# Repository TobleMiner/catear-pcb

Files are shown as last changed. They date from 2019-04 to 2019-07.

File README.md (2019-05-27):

Nekomimi PCB
============

This repo contains the PCB for the Nekomimi project of @BenBE . It will be used
to illuminate 3D printed catears.

This is a short Video of two RevA circuit boards wired up for testing:  

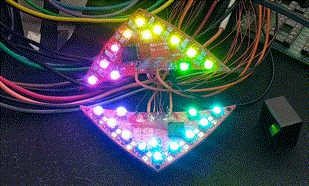
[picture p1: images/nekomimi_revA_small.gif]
RevA PCB pair in action


# PCB top
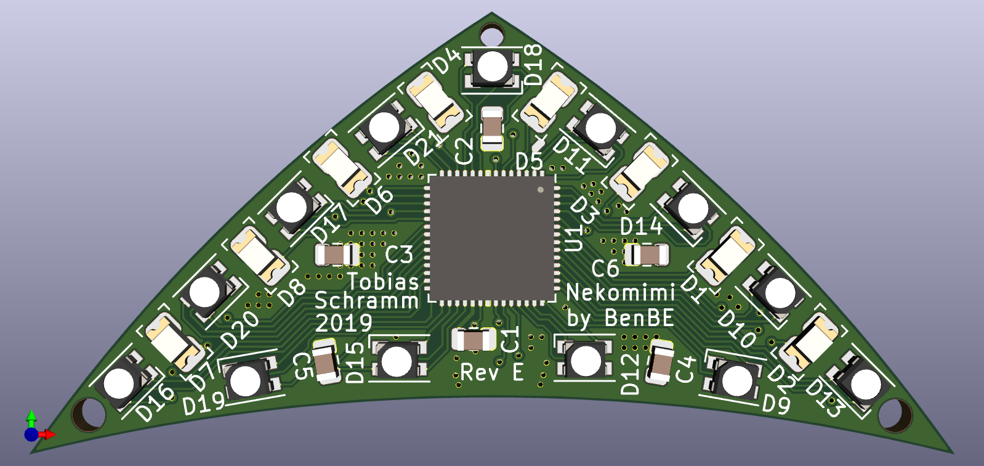
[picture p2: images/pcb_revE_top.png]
PCB RevC top


# PCB bottom
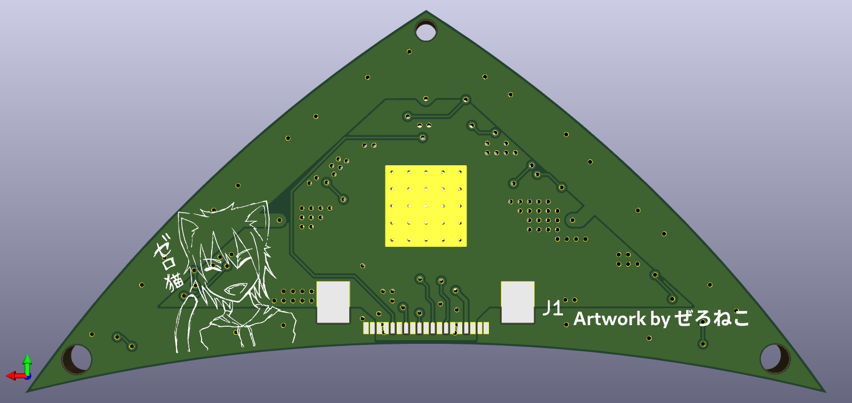
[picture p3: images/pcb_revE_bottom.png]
PCB RevC bottom


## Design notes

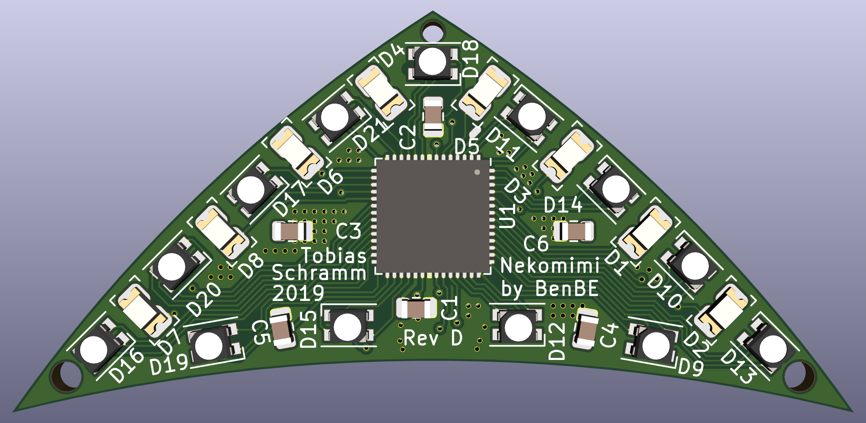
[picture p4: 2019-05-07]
images/pcb_revD_top.png

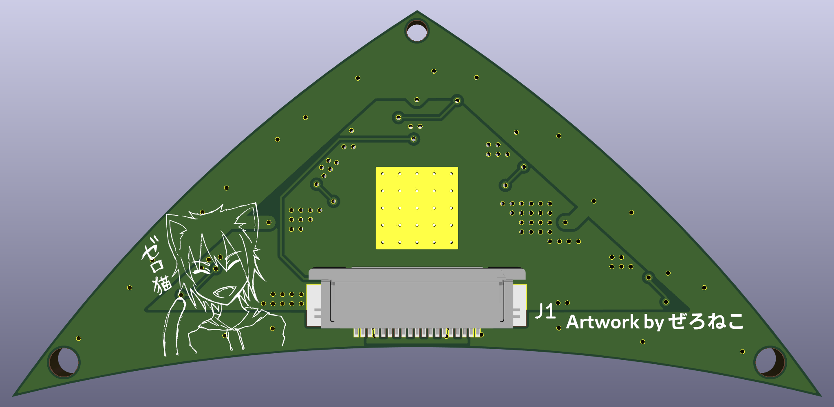
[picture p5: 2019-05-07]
images/pcb_revD_bottom.png

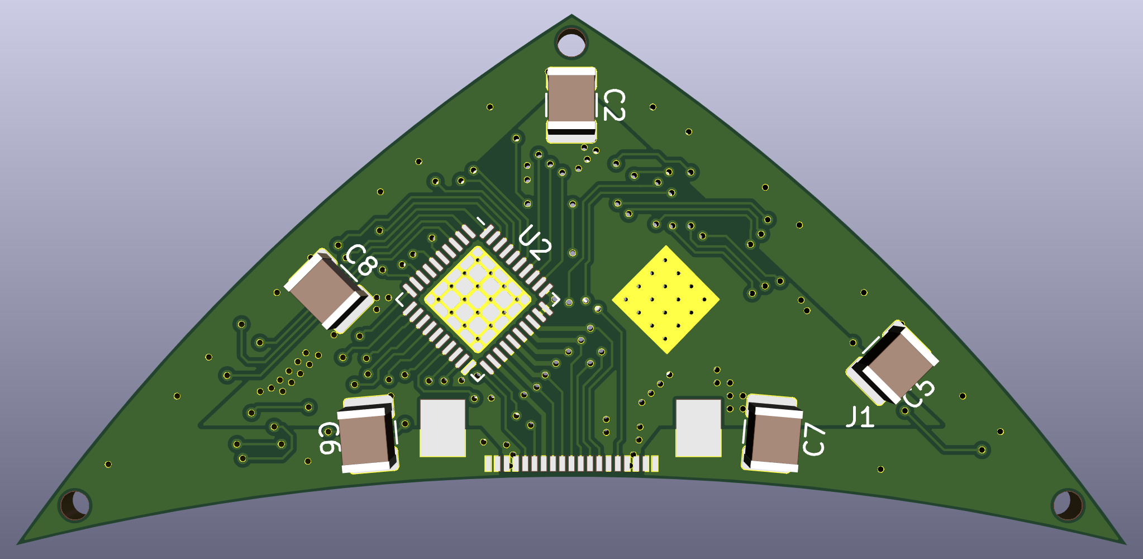
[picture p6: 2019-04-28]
images/pcb_revC_bottom.png

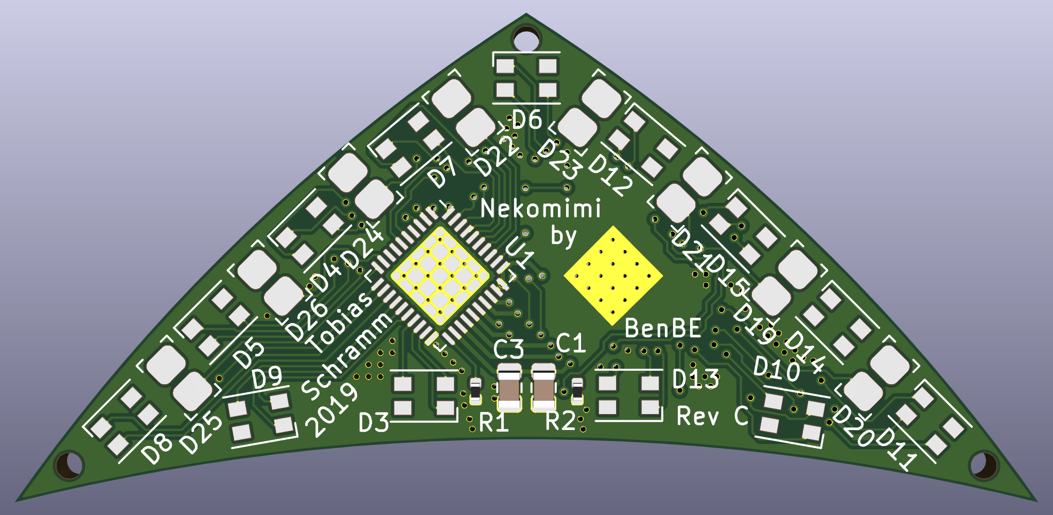
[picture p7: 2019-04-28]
images/pcb_revC_top.png

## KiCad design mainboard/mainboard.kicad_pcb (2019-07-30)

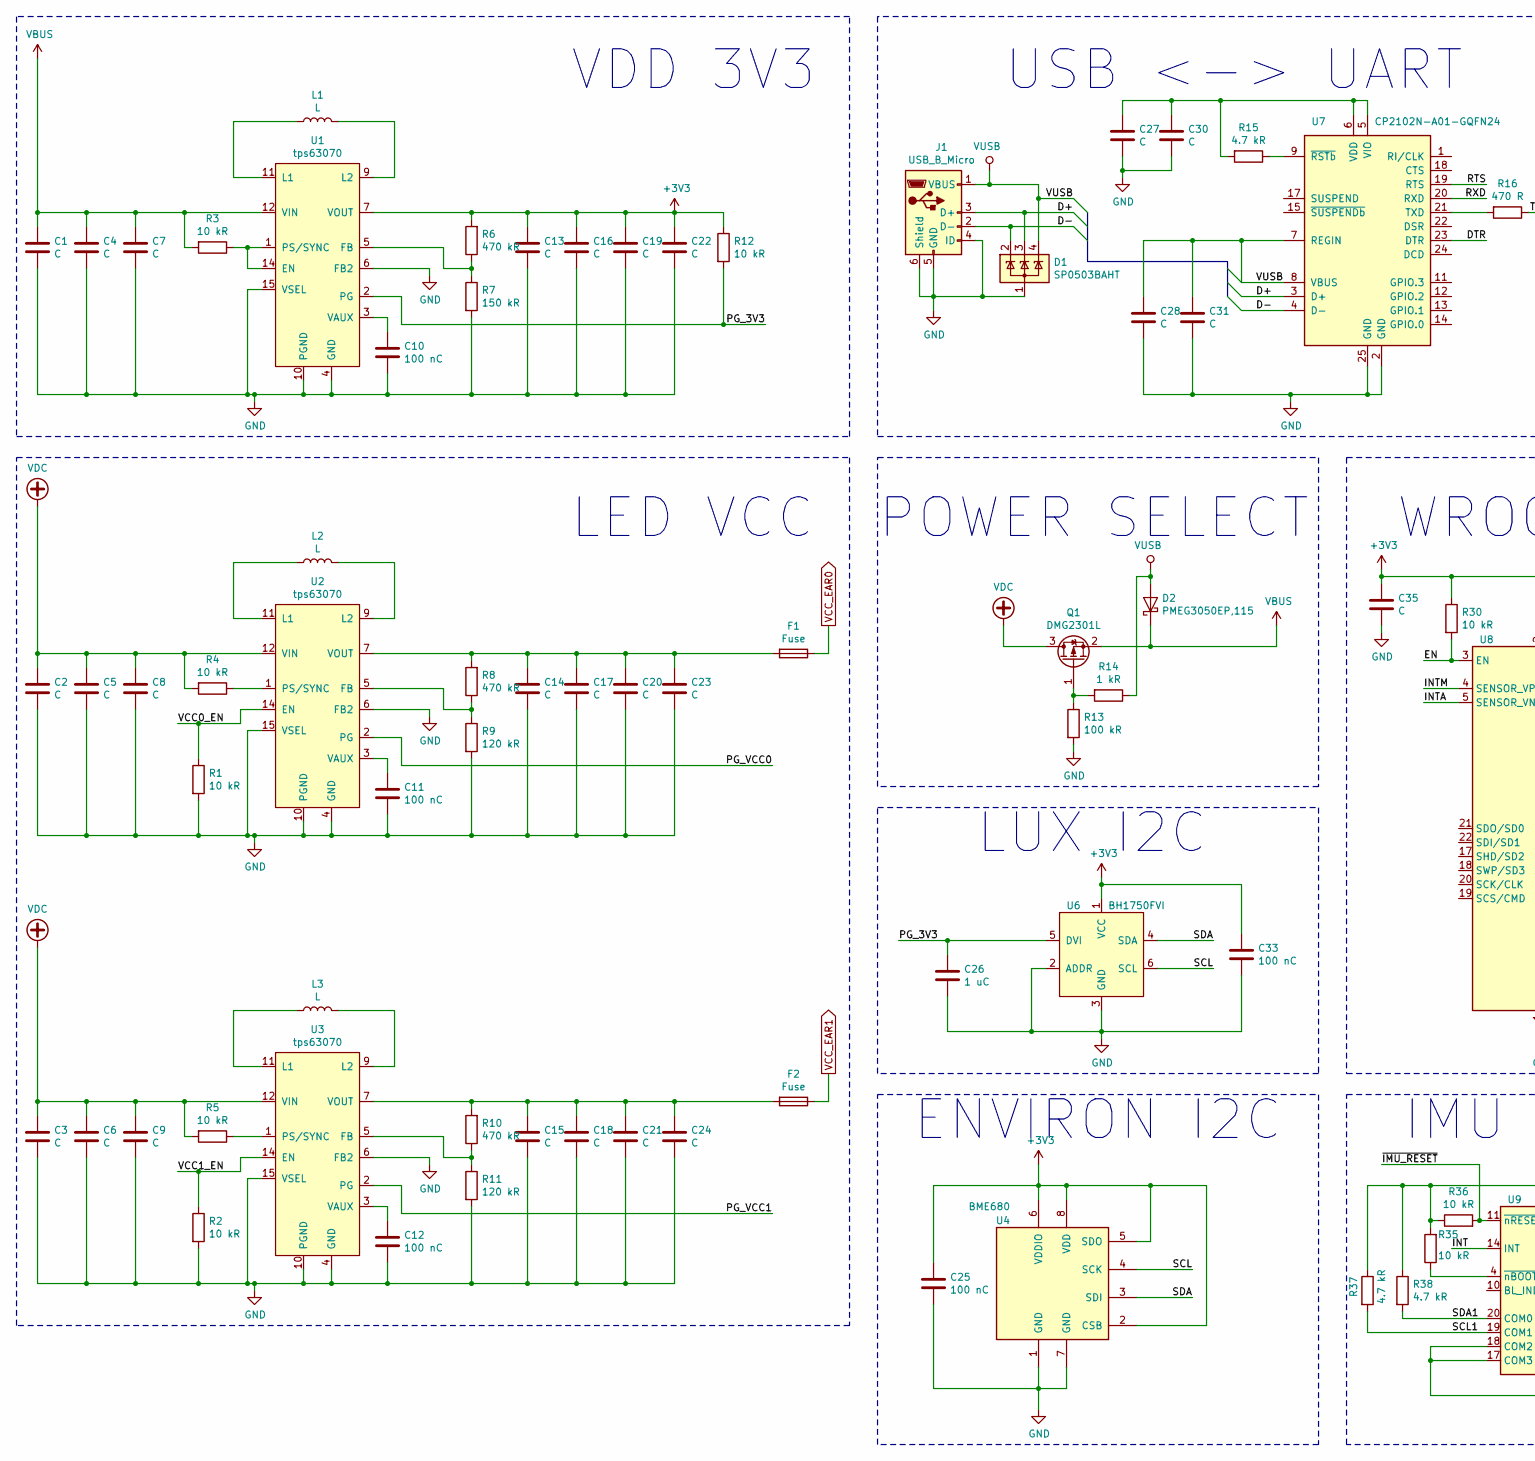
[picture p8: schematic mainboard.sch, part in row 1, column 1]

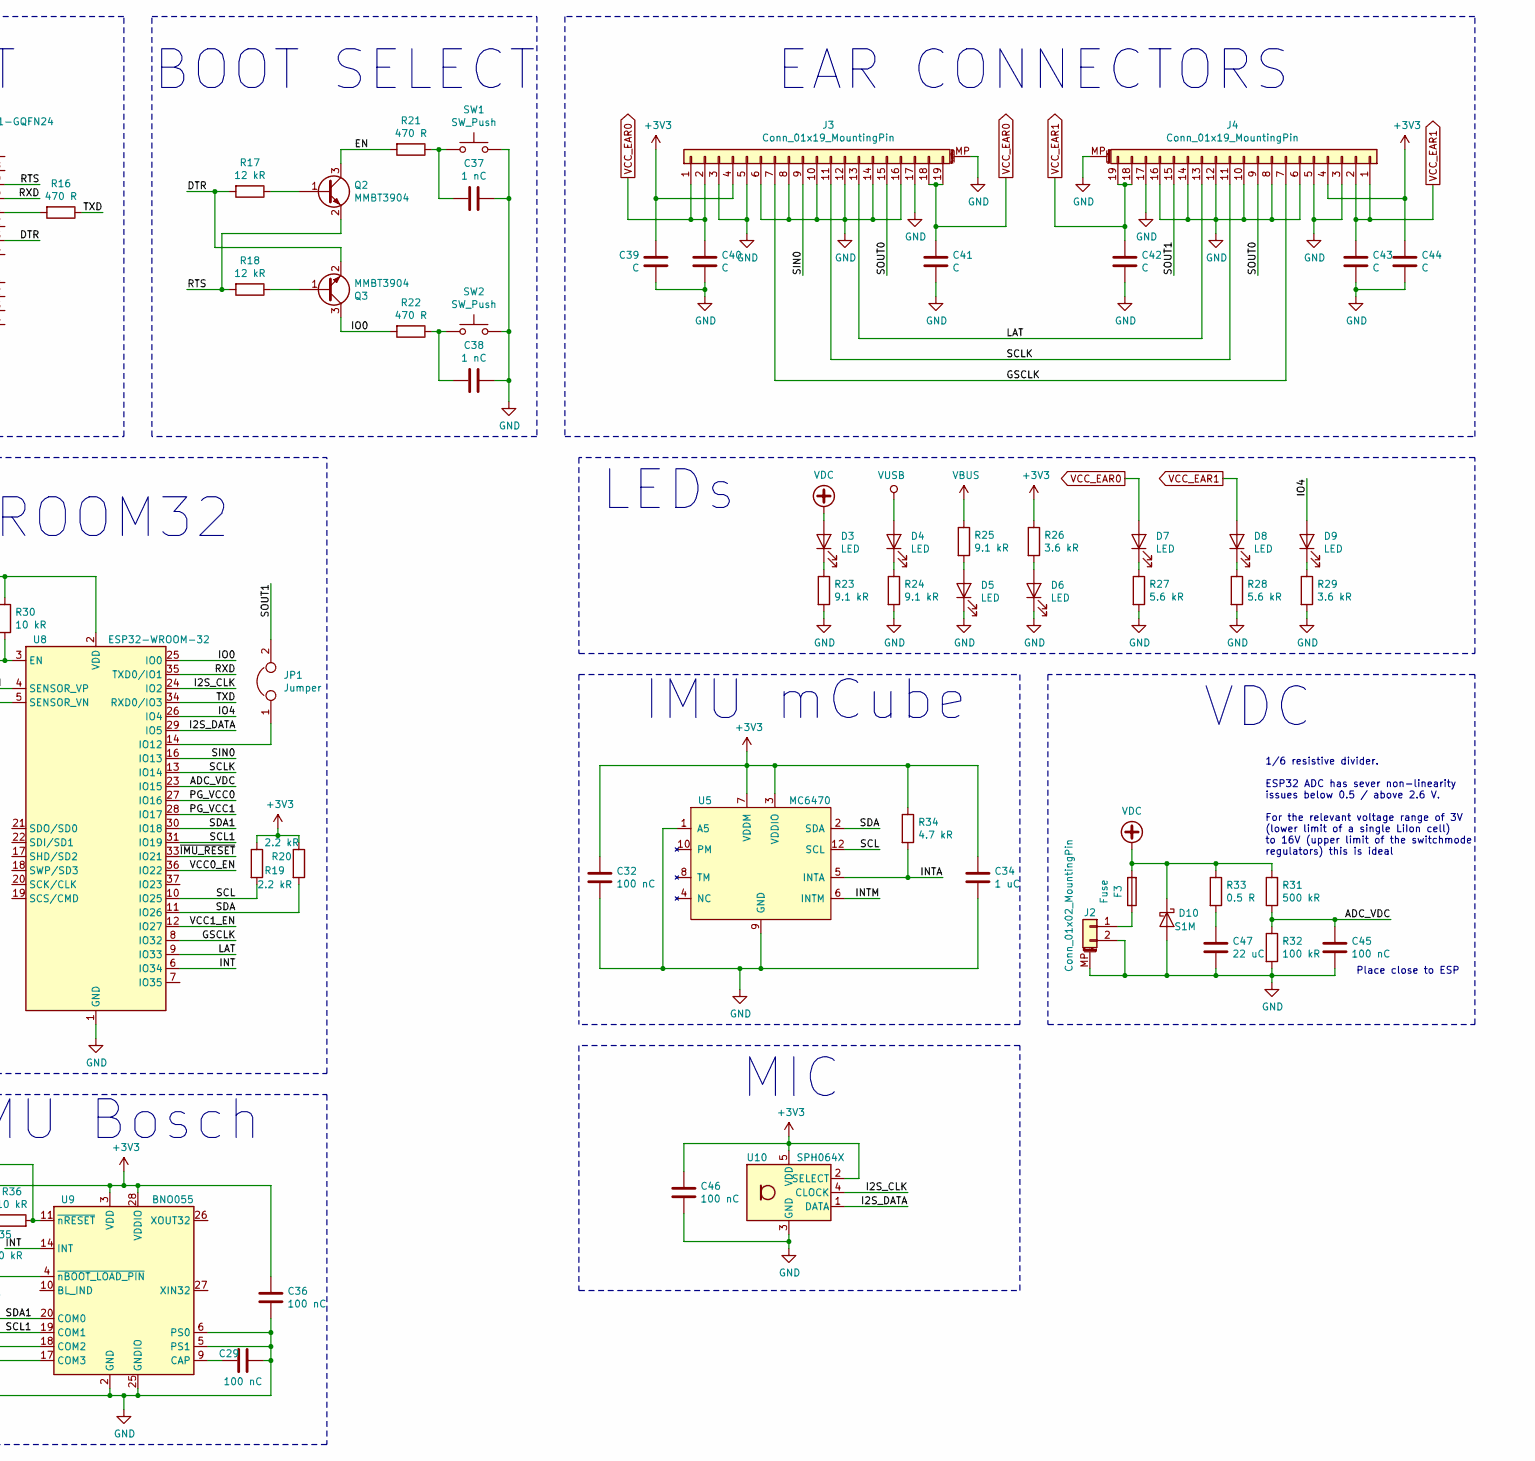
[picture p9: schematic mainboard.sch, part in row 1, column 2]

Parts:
C1, C2, C3, C4, C5, C6, C16, C17, C18, C19, C20, C21, C22, C23, C24, C27, C28, C30, C31, C35, C39, C40, C41, C42, C43, C44: C; C_0805_2012Metric
C7, C8, C9, C13, C14, C15: C; C_0603_1608Metric
C10, C11, C12, C25, C29, C32, C33, C36, C45, C46: 100 nC; C_0805_2012Metric
C26, C34: 1 uC; C_0805_2012Metric
C37, C38: 1 nC; C_0805_2012Metric
C47: 22 uC; C_1210_3225Metric
D1: SP0503BAHT; SOT-143
D2: PMEG3050EP,115; SOD-128-2
D3, D4, D5, D6, D7, D8, D9: LED; LED_0805_2012Metric
D10: S1M; D_SMA
F1, F2: Fuse; Fuse_0805_2012Metric
F3: Fuse; Fuse_1206_3216Metric
J1: USB_B_Micro; USB_Micro-B_Amphenol_10103594-0001LF_Horizontal
J2: Conn_01x02_MountingPin; XT30PW
J3, J4: Conn_01x19_MountingPin; Molex_Easy-On_52746-1971_1x19_P0.5mm_Horizontal
JP1: Jumper; SolderJumper-2_P1.3mm_Bridged_Pad1.0x1.5mm
L1, L2, L3: L; L_Coilcraft_XxL4020
Q1: DMG2301L; SOT-23
Q2, Q3: MMBT3904; SOT-23
R1, R2, R3, R4, R5, R12, R30, R35, R36: 10 kR; R_0805_2012Metric
R6, R8, R10: 470 kR; R_0805_2012Metric
R7: 150 kR; R_0805_2012Metric
R9, R11: 120 kR; R_0805_2012Metric
R13, R32: 100 kR; R_0805_2012Metric
R14: 1 kR; R_0805_2012Metric
R15, R34, R37, R38: 4.7 kR; R_0805_2012Metric
R16, R21, R22: 470 R; R_0805_2012Metric
R17, R18: 12 kR; R_0805_2012Metric
R19, R20: 2.2 kR; R_0805_2012Metric
R23, R24, R25: 9.1 kR; R_0805_2012Metric
R26, R29: 3.6 kR; R_0805_2012Metric
R27, R28: 5.6 kR; R_0805_2012Metric
R31: 500 kR; R_0805_2012Metric
R33: 0.5 R; R_1210_3225Metric
SW1, SW2: SW_Push; SW_Push_SPST_NO_Alps_SKRK
U1, U2, U3: tps63070; VQFN-HR-15
U4: BME680; Bosch_LGA-8_3x3mm_P0.8mm_ClockwisePinNumbering
U5: MC6470; LGA-12_2x2mm_P0.5mm
U6: BH1750FVI; WSOF6I
U7: CP2102N-A01-GQFN24; QFN-24-1EP_4x4mm_P0.5mm_EP2.6x2.6mm
U8: ESP32-WROOM-32
U9: BNO055; LGA-28_5.2x3.8mm_P0.5mm
U10: SPH064X

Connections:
+3V3: C13.1, C16.1, C19.1, C22.1, C25.1, C32.1, C33.1, C34.1, C35.1, C36.1, C39.1, C44.1, C46.1, J3.4, J4.4, R6.2, R12.1, R19.1, R20.1, R26.1, R30.1, R34.1, R35.2, R36.1, R37.1, R38.1, U1.7 (VOUT), U4.2 (CSB), U4.5 (SDO), U4.6 (VDDIO), U4.8 (VDD), U5.3 (VDDIO), U5.7 (VDDM), U6.1 (VCC), U8.2 (VDD), U9.3 (VDD), U9.28 (VDDIO), U10.2 (SELECT), U10.5 (VDD)
/ADC_VDC: C45.1, R31.1, R32.1, U8.23 (IO15)
/D+: D1.3 (K), J1.3 (D+), U7.3 (D+)
/D-: D1.2 (K), J1.2 (D-), U7.4 (D-)
/DTR: Q3.2 (E), R17.2, U7.23 (DTR)
/EN: Q2.3 (C), R21.2, R30.2, U8.3 (EN)
/GSCLK: J3.7, J4.7, U8.8 (IO32)
/I2S_CLK: U8.24 (IO2), U10.4 (CLOCK)
/I2S_DATA: U8.29 (IO5), U10.1 (DATA)
/INT: U8.6 (IO34), U9.14 (INT)
/INTA: R34.2, U5.5 (INTA), U8.5 (SENSOR_VN)
/INTM: U5.6 (INTM), U8.4 (SENSOR_VP)
/IO0: Q3.3 (C), R22.2, U8.25 (IO0)
/IO4: D9.2 (A), U8.26 (IO4)
/LAT: J3.13, J4.13, U8.9 (IO33)
/PG_3V3: C26.1, R12.2, U1.2 (PG), U6.5 (DVI)
/PG_VCC0: U2.2 (PG), U8.27 (IO16)
/PG_VCC1: U3.2 (PG), U8.28 (IO17)
/RTS: Q2.2 (E), R18.2, U7.19 (RTS)
/RXD: U7.20 (RXD), U8.35 (TXD0/IO1)
/SCL: R19.2, U4.4 (SCK), U5.12 (SCL), U6.6 (SCL), U8.10 (IO25)
/SCL1: R37.2, U8.31 (IO19), U9.19 (COM1)
/SCLK: J3.11, J4.11, U8.13 (IO14)
/SDA: R20.2, U4.3 (SDI), U5.2 (SDA), U6.4 (SDA), U8.11 (IO26)
/SDA1: R38.2, U8.30 (IO18), U9.20 (COM0)
/SIN0: J3.9, U8.16 (IO13)
/SOUT0: J3.15, J4.9
/SOUT1: J4.15, JP1.2
/TXD: R16.1, U8.34 (RXD0/IO3)
/VCC0_EN: R1.1, U2.14 (EN), U8.36 (IO22)
/VCC1_EN: R2.1, U3.14 (EN), U8.12 (IO27)
/~IMU_RESET: R36.2, U8.33 (IO21), U9.11 (~nRESET)
GND: C1.2, C2.2, C3.2, C4.2, C5.2, C6.2, C7.2, C8.2, C9.2, C10.2, C11.2, C12.2, C13.2, C14.2, C15.2, C16.2, C17.2, C18.2, C19.2, C20.2, C21.2, C22.2, C23.2, C24.2, C25.2, C26.2, C27.2, C28.2, C29.2, C30.2, C31.2, C32.2, C33.2, C34.2, C35.2, C36.2, C37.1, C38.1, C39.2, C40.2, C41.2, C42.2, C43.2, C44.2, C45.2, C46.2, C47.2, D1.1 (A), D5.1 (K), D6.1 (K), D10.2 (A), J1.4 (ID), J1.5 (GND), J1.6 (Shield), J2.2, J2.MP (MountPin), J3.3, J3.5, J3.6, J3.8, J3.10, J3.12, J3.14, J3.16, J3.17, J3.MP (MountPin), J4.3, J4.5, J4.6, J4.8, J4.10, J4.12, J4.14, J4.16, J4.17, J4.MP (MountPin), R1.2, R2.2, R7.2, R9.2, R11.2, R13.2, R23.2, R24.2, R27.2, R28.2, R29.2, R32.2, SW1.2, SW2.2, U1.4 (GND), U1.6 (FB2), U1.10 (PGND), U1.15 (VSEL), U2.4 (GND), U2.6 (FB2), U2.10 (PGND), U2.15 (VSEL), U3.4 (GND), U3.6 (FB2), U3.10 (PGND), U3.15 (VSEL), U4.1 (GND), U4.7 (GND), U5.1 (A5), U5.9 (GND), U6.2 (ADDR), U6.3 (GND), U7.2 (GND), U7.25 (GND), U8.1 (GND), U8.15 (GND), U8.38 (GND), U8.39 (GND), U9.2 (GND), U9.5 (PS1), U9.6 (PS0), U9.15 (GNDIO), U9.16 (GNDIO), U9.17 (COM3), U9.18 (COM2), U9.25 (GNDIO), U10.3 (GND)
unnamed: C10.1, U1.3 (VAUX)
unnamed: C11.1, U2.3 (VAUX)
unnamed: C12.1, U3.3 (VAUX)
unnamed: C14.1, C17.1, C20.1, C23.1, F1.2, R8.2, U2.7 (VOUT)
unnamed: C15.1, C18.1, C21.1, C24.1, F2.2, R10.2, U3.7 (VOUT)
unnamed: C27.1, C30.1, R15.2, U7.5 (VIO), U7.6 (VDD)
unnamed: C29.1, U9.9 (CAP)
unnamed: C37.2, R21.1, SW1.1
unnamed: C38.2, R22.1, SW2.1
unnamed: C47.1, R33.2
unnamed: D3.1 (K), R23.1
unnamed: D4.1 (K), R24.1
unnamed: D5.2 (A), R25.2
unnamed: D6.2 (A), R26.2
unnamed: D7.1 (K), R27.1
unnamed: D8.1 (K), R28.1
unnamed: D9.1 (K), R29.1
unnamed: F3.1, J2.1
unnamed: JP1.1, U8.14 (IO12)
unnamed: L1.1, U1.11 (L1)
unnamed: L1.2, U1.9 (L2)
unnamed: L2.1, U2.11 (L1)
unnamed: L2.2, U2.9 (L2)
unnamed: L3.1, U3.11 (L1)
unnamed: L3.2, U3.9 (L2)
unnamed: Q1.1 (G), R13.1, R14.2
unnamed: Q2.1 (B), R17.1
unnamed: Q3.1 (B), R18.1
unnamed: R3.1, U1.1 (PS/SYNC), U1.14 (EN)
unnamed: R4.1, U2.1 (PS/SYNC)
unnamed: R5.1, U3.1 (PS/SYNC)
unnamed: R6.1, R7.1, U1.5 (FB)
unnamed: R8.1, R9.1, U2.5 (FB)
unnamed: R10.1, R11.1, U3.5 (FB)
unnamed: R15.1, U7.9 (~RSTb)
unnamed: R16.2, U7.21 (TXD)
unnamed: R35.1, U9.4 (~nBOOT_LOAD_PIN)
VBUS: C1.1, C4.1, C7.1, D2.1 (K), Q1.2 (S), R3.2, R25.1, U1.12 (VIN)
VCC_EAR0: C40.1, C41.1, D7.2 (A), F1.1, J3.1, J3.2, J3.18, J3.19
VCC_EAR1: C42.1, C43.1, D8.2 (A), F2.1, J4.1, J4.2, J4.18, J4.19
VDC: C2.1, C3.1, C5.1, C6.1, C8.1, C9.1, D3.2 (A), D10.1 (K), F3.2, Q1.3 (D), R4.2, R5.2, R31.2, R33.1, U2.12 (VIN), U3.12 (VIN)
VUSB: C28.1, C31.1, D1.4 (K), D2.2 (A), D4.2 (A), J1.1 (VBUS), R14.1, U7.7 (REGIN), U7.8 (VBUS)

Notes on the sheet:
LED VCC
VDD 3V3
USB <-> UART
POWER SELECT
LUX I2C
ENVIRON I2C
BOOT SELECT
EAR CONNECTORS
WROOM32
IMU Bosch
IMU mCube
VDC
LEDs
1/6 resistive divider. ESP32 ADC has sever non-linearity issues below 0.5 / above 2.6 V. For the relevant voltage range of 3V (lower limit of a single LiIon cell) to 16V (upper limit of the switchmode regulators) this is ideal
Place close to ESP
MIC

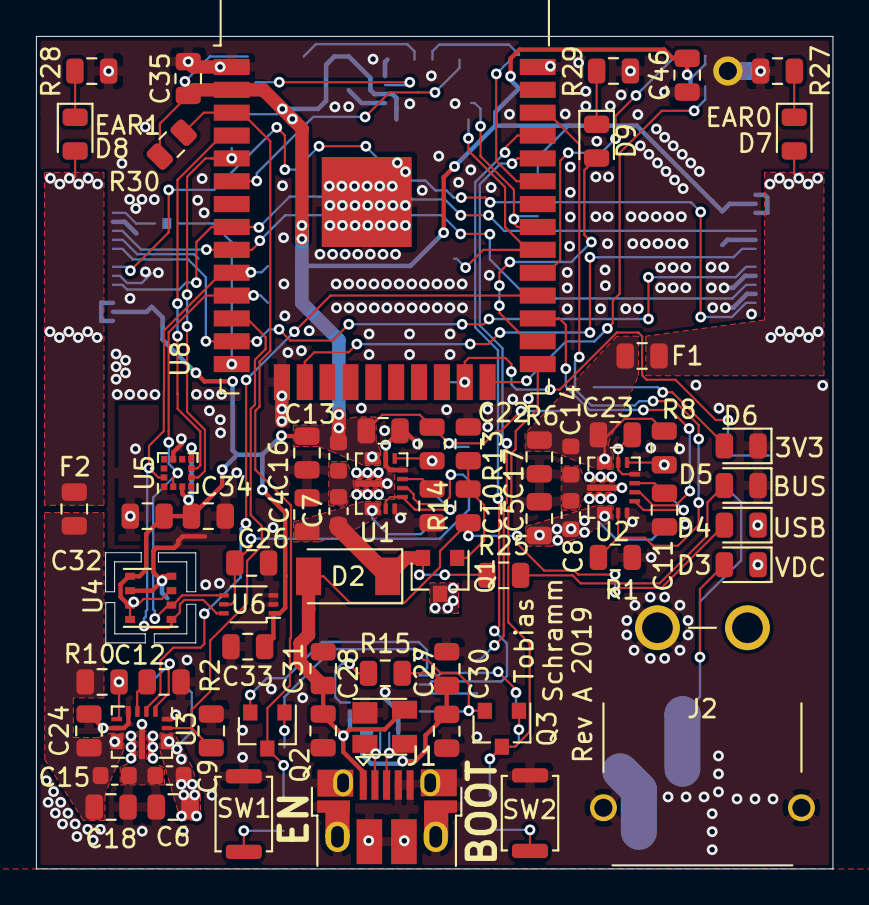
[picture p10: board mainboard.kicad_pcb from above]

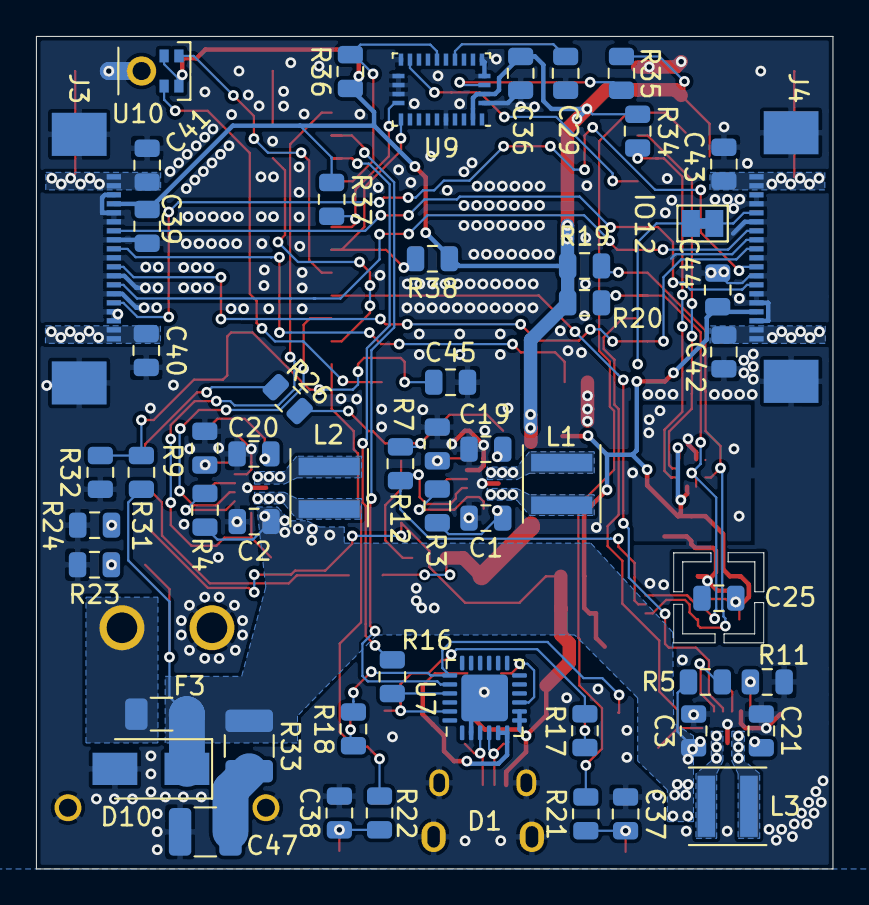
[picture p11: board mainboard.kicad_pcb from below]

Board: 2 copper layers, 44.3 x 46.2 mm, 121 parts (55 on the bottom side), 75 nets.

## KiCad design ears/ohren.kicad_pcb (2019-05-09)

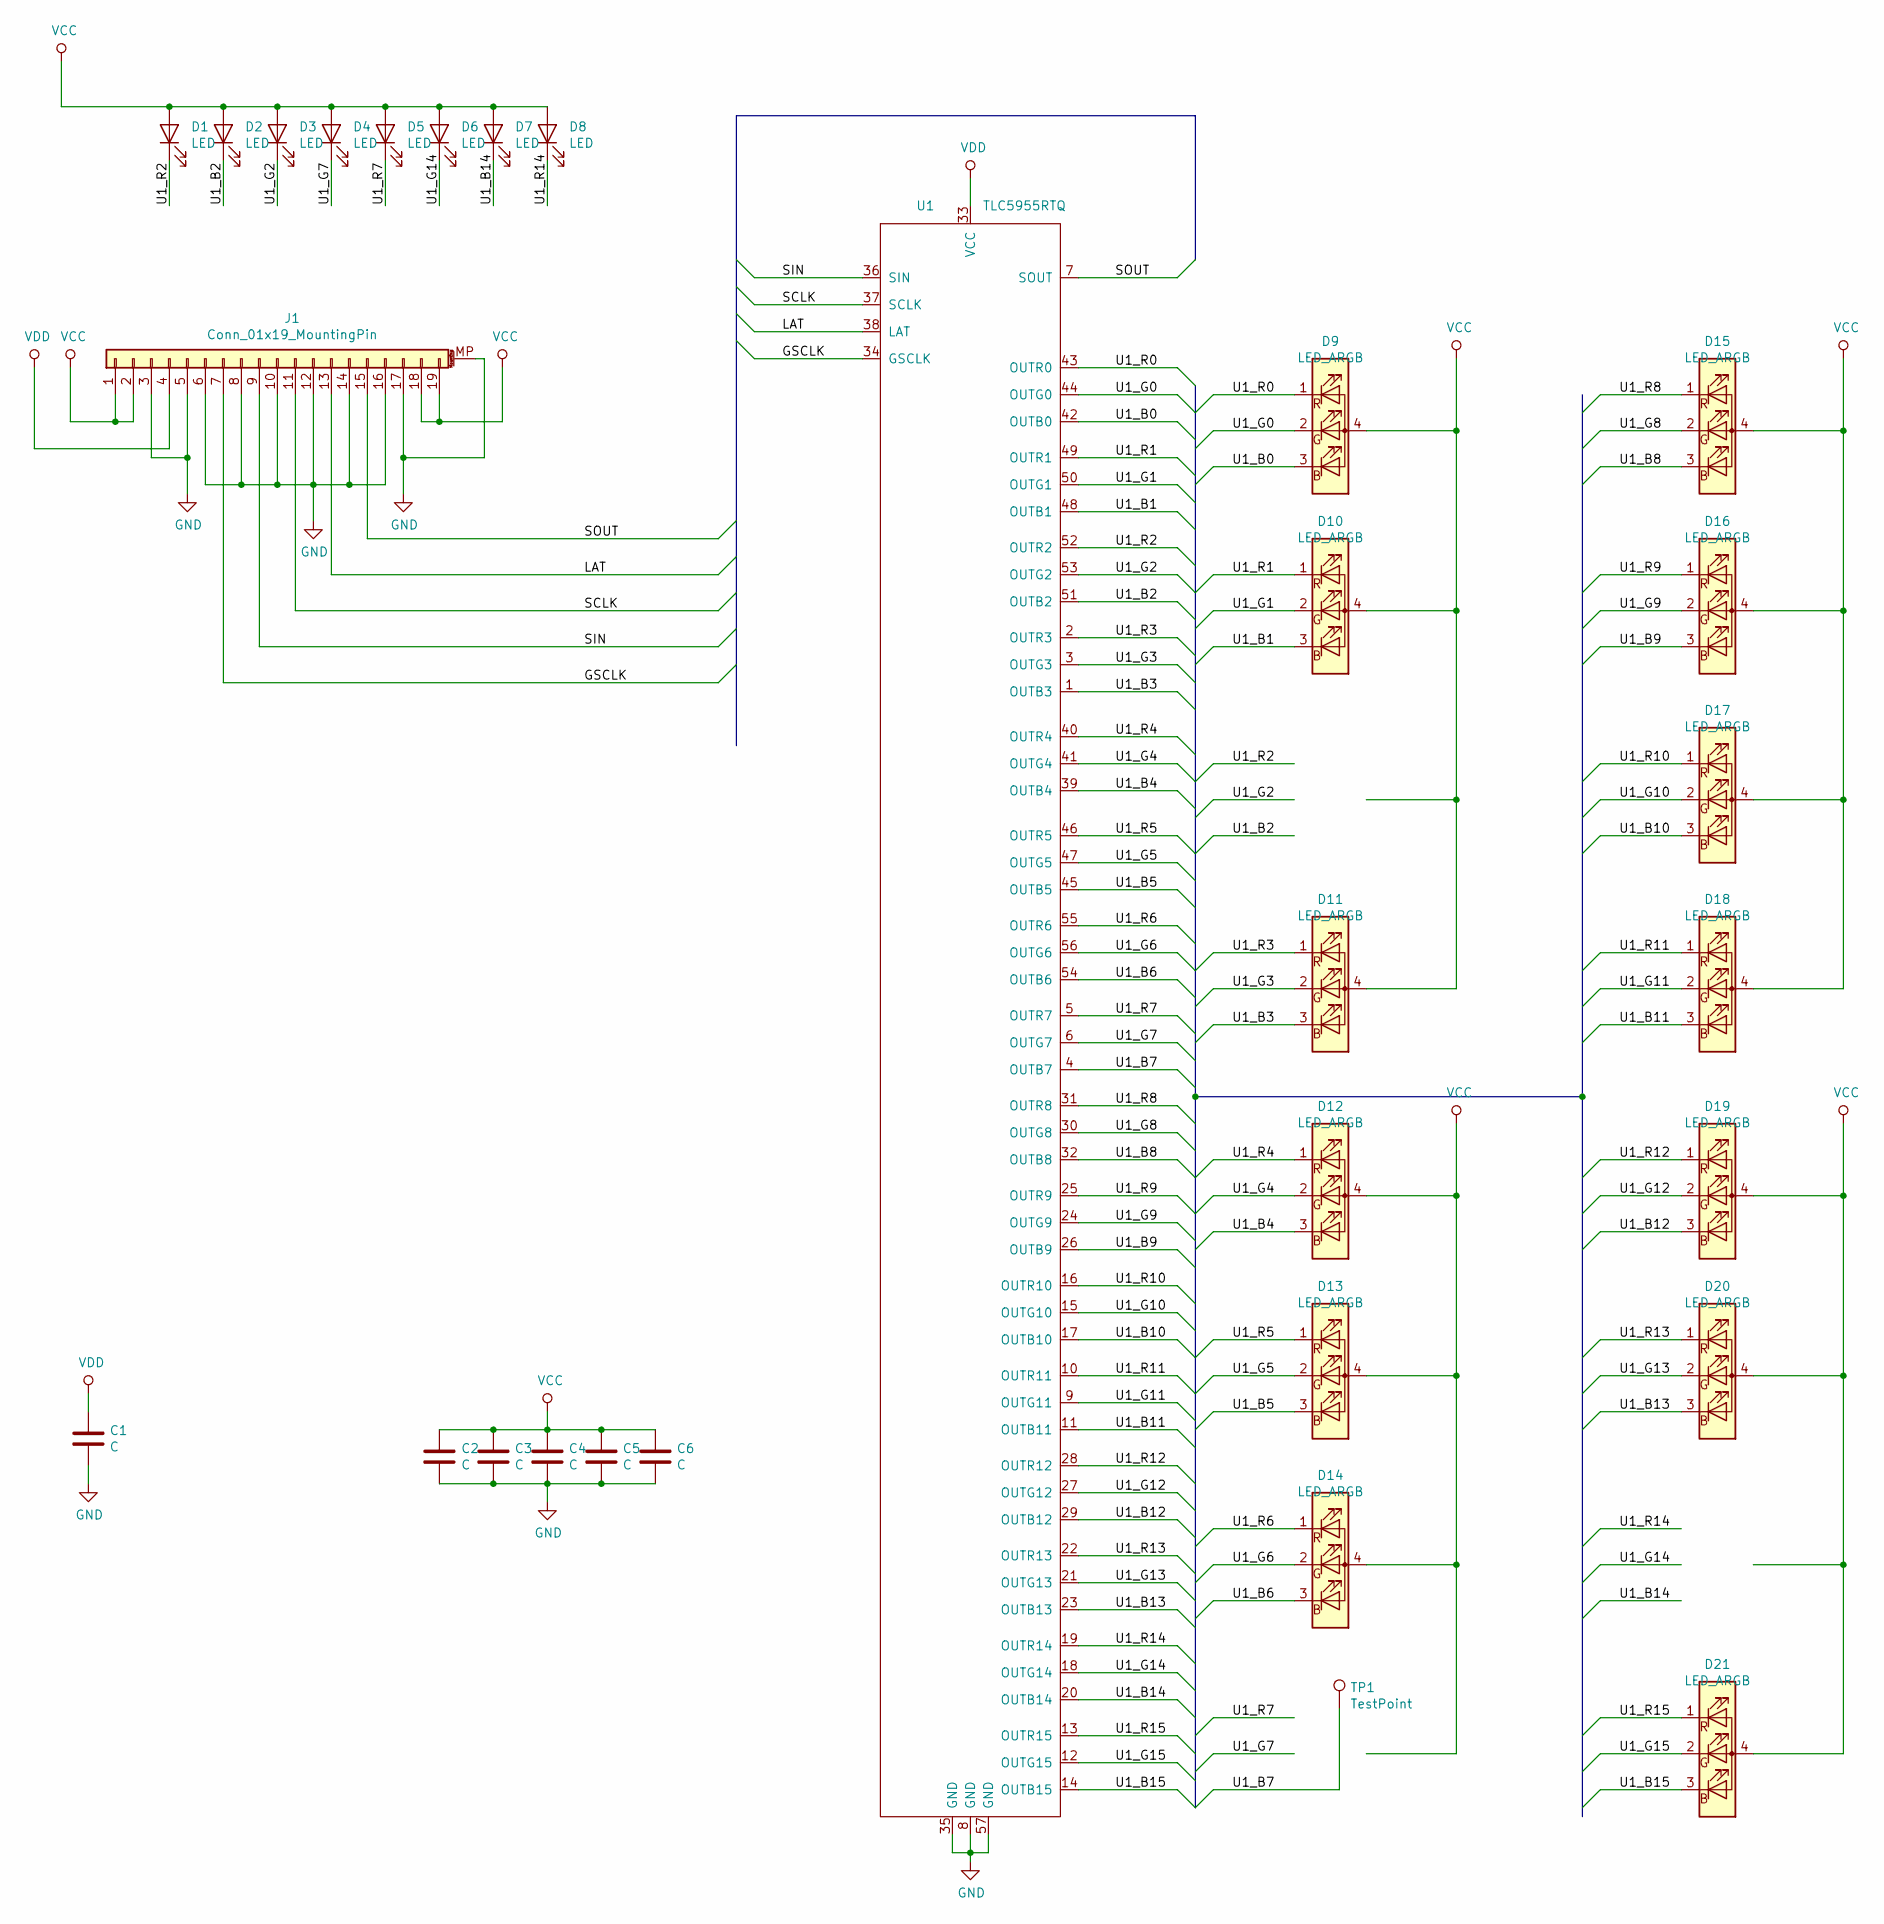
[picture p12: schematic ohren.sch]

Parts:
C1, C2, C3, C4, C5, C6: C; C_0805_2012Metric
D1, D2, D3, D4, D5, D6, D7, D8: LED; smd_led_universal
D9, D10, D11, D12, D13, D14, D15, D16, D17, D18, D19, D20, D21: LED_ARGB; ASMB-MTB1-0A3A2
J1: Conn_01x19_MountingPin; Molex_Easy-On_52746-1971_1x19_P0.5mm_Horizontal
TP1: TestPoint; TestPoint_0.5x1mm
U1: TLC5955RTQ; QFN-56-1EP_8x8mm_P0.5mm_EP5.6x5.6mm_ThermalVias

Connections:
/GSCLK: J1.7, U1.34 (GSCLK)
/LAT: J1.13, U1.38 (LAT)
/SCLK: J1.11, U1.37 (SCLK)
/SIN: J1.9, U1.36 (SIN)
/SOUT: J1.15, U1.7 (SOUT)
/U1_B0: D9.3 (BK), U1.42 (OUTB0)
/U1_B1: D10.3 (BK), U1.48 (OUTB1)
/U1_B2: D2.1 (K), U1.51 (OUTB2)
/U1_B3: D11.3 (BK), U1.1 (OUTB3)
/U1_B4: D12.3 (BK), U1.39 (OUTB4)
/U1_B5: D13.3 (BK), U1.45 (OUTB5)
/U1_B6: D14.3 (BK), U1.54 (OUTB6)
/U1_B7: TP1.1, U1.4 (OUTB7)
/U1_B8: D15.3 (BK), U1.32 (OUTB8)
/U1_B9: D16.3 (BK), U1.26 (OUTB9)
/U1_B10: D17.3 (BK), U1.17 (OUTB10)
/U1_B11: D18.3 (BK), U1.11 (OUTB11)
/U1_B12: D19.3 (BK), U1.29 (OUTB12)
/U1_B13: D20.3 (BK), U1.23 (OUTB13)
/U1_B14: D7.1 (K), U1.20 (OUTB14)
/U1_B15: D21.3 (BK), U1.14 (OUTB15)
/U1_G0: D9.2 (GK), U1.44 (OUTG0)
/U1_G1: D10.2 (GK), U1.50 (OUTG1)
/U1_G2: D3.1 (K), U1.53 (OUTG2)
/U1_G3: D11.2 (GK), U1.3 (OUTG3)
/U1_G4: D12.2 (GK), U1.41 (OUTG4)
/U1_G5: D13.2 (GK), U1.47 (OUTG5)
/U1_G6: D14.2 (GK), U1.56 (OUTG6)
/U1_G7: D4.1 (K), U1.6 (OUTG7)
/U1_G8: D15.2 (GK), U1.30 (OUTG8)
/U1_G9: D16.2 (GK), U1.24 (OUTG9)
/U1_G10: D17.2 (GK), U1.15 (OUTG10)
/U1_G11: D18.2 (GK), U1.9 (OUTG11)
/U1_G12: D19.2 (GK), U1.27 (OUTG12)
/U1_G13: D20.2 (GK), U1.21 (OUTG13)
/U1_G14: D6.1 (K), U1.18 (OUTG14)
/U1_G15: D21.2 (GK), U1.12 (OUTG15)
/U1_R0: D9.1 (RK), U1.43 (OUTR0)
/U1_R1: D10.1 (RK), U1.49 (OUTR1)
/U1_R2: D1.1 (K), U1.52 (OUTR2)
/U1_R3: D11.1 (RK), U1.2 (OUTR3)
/U1_R4: D12.1 (RK), U1.40 (OUTR4)
/U1_R5: D13.1 (RK), U1.46 (OUTR5)
/U1_R6: D14.1 (RK), U1.55 (OUTR6)
/U1_R7: D5.1 (K), U1.5 (OUTR7)
/U1_R8: D15.1 (RK), U1.31 (OUTR8)
/U1_R9: D16.1 (RK), U1.25 (OUTR9)
/U1_R10: D17.1 (RK), U1.16 (OUTR10)
/U1_R11: D18.1 (RK), U1.10 (OUTR11)
/U1_R12: D19.1 (RK), U1.28 (OUTR12)
/U1_R13: D20.1 (RK), U1.22 (OUTR13)
/U1_R14: D8.1 (K), U1.19 (OUTR14)
/U1_R15: D21.1 (RK), U1.13 (OUTR15)
GND: C1.2, C2.2, C3.2, C4.2, C5.2, C6.2, J1.3, J1.5, J1.6, J1.8, J1.10, J1.12, J1.14, J1.16, J1.17, J1.MP (MountPin), U1.8 (GND), U1.35 (GND), U1.57 (GND)
VCC: C2.1, C3.1, C4.1, C5.1, C6.1, D1.2 (A), D2.2 (A), D3.2 (A), D4.2 (A), D5.2 (A), D6.2 (A), D7.2 (A), D8.2 (A), D9.4 (A), D10.4 (A), D11.4 (A), D12.4 (A), D13.4 (A), D14.4 (A), D15.4 (A), D16.4 (A), D17.4 (A), D18.4 (A), D19.4 (A), D20.4 (A), D21.4 (A), J1.1, J1.2, J1.18, J1.19
VDD: C1.1, J1.4, U1.33 (VCC)

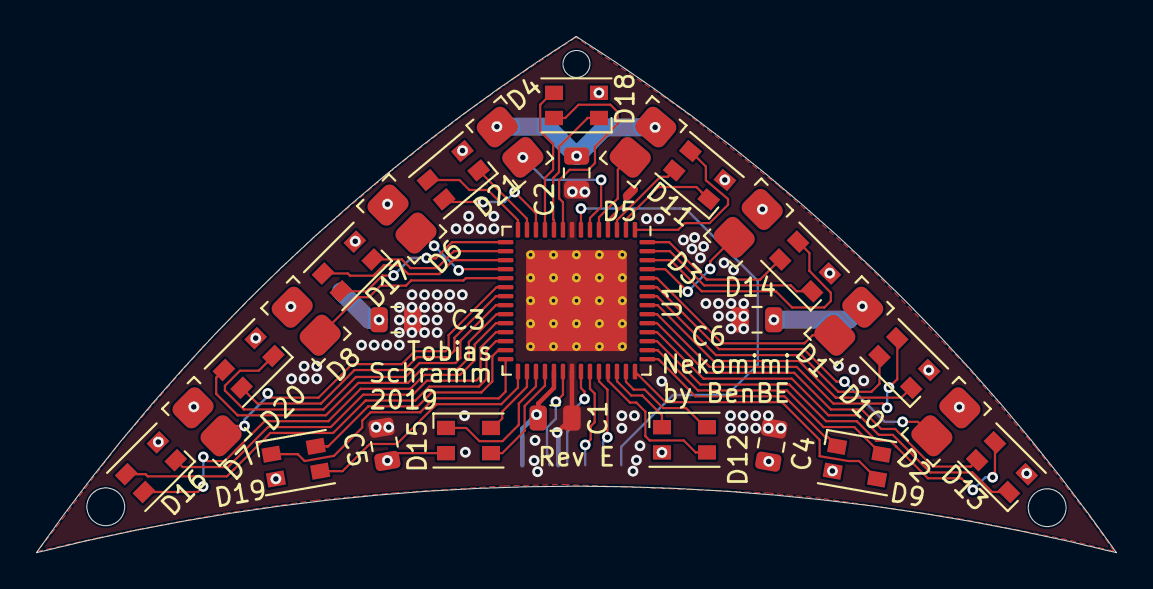
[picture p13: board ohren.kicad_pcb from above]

Board: 2 copper layers, 60.0 x 28.7 mm, 30 parts (1 on the bottom side), 56 nets.

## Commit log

2019-03-25 Add LEDs and drivers
    [ohren.kicad_pcb, ohren.sch]
2019-03-25 Route (sort of) clock and data bus
    [ohren.kicad_pcb]
2019-03-25 Add some bypass capacitance
    [ohren.kicad_pcb, ohren.sch]
2019-03-25 Add GND supports to GND net
    [ohren.kicad_pcb]
2019-03-28 Partial reroute
    [ohren.kicad_pcb, ohren.sch]
2019-03-28 Reroute finised
    [ohren.kicad_pcb, ohren.sch]
2019-03-28 Ignore rendered gerbers
2019-03-28 Add additional VIA stitching and bypass capacitance
    [ohren.kicad_pcb, ohren.sch]
2019-03-28 Add mounting hole
2019-03-28 Add mounting holes
    [ohren.kicad_pcb]
2019-03-28 Add silkscreen designators
    [ohren.kicad_pcb]
2019-04-27 Almost (tm) finish full rerouting
    [ohren.kicad_pcb, ohren.sch]
2019-04-27 Finish layouting
    [ohren.kicad_pcb, ohren.sch]
2019-04-27 Adjust UV LED attachment + U1 LED routing slightly
    Slight changes for better groundplane coverage
    [ohren.kicad_pcb, ohren.sch]
2019-04-27 More GND VIA stitching
    [ohren.kicad_pcb]
2019-04-27 Pull down bottom center GND plane a little
    Fixes MP of flatflex connector reporting as not connected
    [ohren.kicad_pcb]
2019-04-27 Move build year off of VIAs
    [ohren.kicad_pcb]
2019-04-27 Move silkscreen component designators to unobstructed places
    [ohren.kicad_pcb]
2019-04-27 Switch to more readily available Molex Easy-On 52746 series FFC
    [ohren.kicad_pcb, ohren.sch]
2019-04-27 Move up FFC slightly
    Ensures that pads won't be damaged when milling the PCB
    [ohren.kicad_pcb]
2019-04-27 Move design year away from VIAs
    [ohren.kicad_pcb]
2019-04-27 Remove stray via
    [ohren.kicad_pcb]
2019-04-27 Maximize groundplane cooling capacity on U1
    [ohren.kicad_pcb]
2019-04-27 Reroute GSSOUT and DCSOUT to optimize cooling of U2
    [ohren.kicad_pcb]
2019-04-27 Add additional via stitching to GND of U2
    [ohren.kicad_pcb]
2019-04-27 Add via stitching to low-impedance cap GNDs
    [ohren.kicad_pcb]
2019-05-02 Design revision D
    [ohren.kicad_pcb, ohren.sch]
2019-05-02 Revise connector layout
    [ohren.kicad_pcb, ohren.sch]
2019-05-02 Readjust silkscreen designators
    [ohren.kicad_pcb]
2019-05-02 Remove obsolete measurement
    [ohren.kicad_pcb]
2019-05-02 Hide silkscreen designators of mounting holes
    [ohren.kicad_pcb]
2019-05-02 Add Artwork
    [ohren.kicad_pcb]
2019-05-02 Add artwork attribution
    [ohren.kicad_pcb]
2019-05-03 Optimize GND via stitching
    [ohren.kicad_pcb]
2019-05-03 Add TP to unused TLC pin
    [ohren.kicad_pcb, ohren.sch]
2019-05-03 Readjust silkscreen designators around TP1
    [ohren.kicad_pcb]
2019-05-03 Reassign component references
    [ohren.kicad_pcb, ohren.sch]
2019-05-03 Move D5 designator to a more convenient place
    [ohren.kicad_pcb]
2019-05-03 Reroute U1_B9
    [ohren.kicad_pcb]
2019-05-03 Move D18 VCC via to center of VCC pad
    [ohren.kicad_pcb]
2019-05-07 Add LED 3D models
    [ohren.kicad_pcb]
2019-05-07 Add 3d connector model
    [ohren.kicad_pcb]
2019-05-07 Use custom LED footprint with associated 3D model
    [ohren.kicad_pcb, ohren.sch]
2019-05-07 Update PCB renders
2019-05-09 Fix LED footprint
2019-05-09 Fix RGB LED routing
    [ohren.kicad_pcb]
2019-06-06 Move ears to separate directory
    [ohren-B_Cu.gbl, ohren-B_Mask.gbs, ohren-B_Paste.gbp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]
2019-06-06 Mainboard WIP
    [mainboard.kicad_pcb, mainboard.sch]
2019-06-06 Add basic circuitry
    [mainboard.sch]
2019-06-06 Add sensors
    [mainboard.kicad_pcb, mainboard.sch]
2019-06-07 Add accelerometer and magnetometer
    [mainboard.sch]
2019-06-07 Layouting WIP
    [mainboard.kicad_pcb, mainboard.sch]
2019-06-07 Assemble regulator sections
    [mainboard.kicad_pcb, mainboard.sch]
2019-06-08 Move components to sane-ish positions
    [mainboard.kicad_pcb]
2019-06-08 Separate switchmode regulator power and digital ground
    [mainboard.kicad_pcb]
2019-06-08 Add right-angle XT30 power connector
    [mainboard.kicad_pcb, mainboard.sch]
2019-06-08 More WIP
    [mainboard.kicad_pcb, mainboard.sch]
2019-06-08 Yet more WIP
    [mainboard.kicad_pcb]
2019-06-08 Finish basic routing
    [mainboard.kicad_pcb, mainboard.sch]
2019-06-08 More GND stitching
    [mainboard.kicad_pcb]
2019-06-08 Adjust silkscreen designators for readability
    [mainboard.kicad_pcb]
2019-06-08 Connect XT30 mounting pins to ground
    [mainboard.kicad_pcb, mainboard.sch]
2019-06-08 Fix designator of R29
    [mainboard.kicad_pcb]
2019-06-08 Reassign silkscreen designators
    [mainboard.kicad_pcb, mainboard.sch]
2019-06-09 More ground stitching
    [mainboard.kicad_pcb]
2019-06-09 Add revision indicator
    [mainboard.kicad_pcb]
2019-07-13 Replace reset circuitry
    It was the reference circuit used on the DevKitC V4 but it just plain does not work.
    Replaced by much simpler and more reliable design.
    [mainboard.kicad_pcb, mainboard.sch]
2019-07-24 Revert "Replace reset circuitry"
    This reverts commit 4aa51ba1305b71722c80cb68cdfb79191ae487c4.
    CP2102N defaults to RTS + CTS high. Thus the reference reset circuitry is the only
    simple way to make this work
    [mainboard.kicad_pcb, mainboard.sch]
2019-07-24 Add ~RESET pullup
    [mainboard.kicad_pcb, mainboard.sch]
2019-07-24 Add WROOM-32 with GND pad
    [mainboard.sch]
2019-07-24 Swap RXD and TXD
    [mainboard.kicad_pcb, mainboard.sch]
2019-07-24 Adjust LED resistors for less eye piercing brightness
    Green LEDs really are bright. Reduce current to ~300 µA
    [mainboard.sch]
2019-07-24 Add VDC voltage measurement divider
    [mainboard.kicad_pcb, mainboard.sch]
2019-07-24 Optimize ground
    [mainboard.kicad_pcb]
2019-07-24 Add pdm microphone
    [mainboard.kicad_pcb, mainboard.sch]
2019-07-24 Improve separation between I2S_CLK and I2S_DATA
    [mainboard.kicad_pcb]
2019-07-24 Improve GND impedance around U10
    [mainboard.kicad_pcb]
2019-07-24 Add VDC input protection
    [mainboard.kicad_pcb, mainboard.sch]
2019-07-24 Fix inconsistent designator rotation
    [mainboard.kicad_pcb]
2019-07-29 Replace magnetometer by MC6470
    [mainboard.kicad_pcb, mainboard.sch]
2019-07-29 Replace accelerometer by BNO055
    [mainboard.kicad_pcb, mainboard.sch]
2019-07-30 Move R34 to bottom layer
    [mainboard.kicad_pcb]
